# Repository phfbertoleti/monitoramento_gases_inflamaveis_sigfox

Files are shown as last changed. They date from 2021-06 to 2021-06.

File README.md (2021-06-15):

# Monitoramento de gases inflamáveis com SigFox

Este repositório contém o projeto (hardware e software) do monitoramento de gases inflamáveis com SigFox.

## Componentes

Este projeto utiliza os seguinte componentes e placas:

* Placa Edukit SigFox (link para aquisição: https://www.curtocircuito.com.br/kit-iot-sigfox-com-edukit-redfox.html), que utiliza um HT32SX para comunicação SigFox
* Placa Arduino Nano
* Sensor MQ-2
* Sensor DHT11
* Resistor de 10k / 0.25W
* Protoboard de 400 pontos
* Jumpers diversos

## Funcionamento simplificado

O funcionamento simplificado do projeto é:

1. O Arduino Nano faz, periodicamente (uma vez por segundo), a leitura dos sensores DHT11 e MQ-2.
2. Uma vez a cada meia hora o Arduino Nano envia, através do HT32SX, as leituras para a rede SigFox. A comunicação entre Arduino Nano e HT32SX é feita via UART, com comandos AT.
3. Uma vez recebido por um ou mais gateways, os dados enviados vão para o backend SigFox e redirecionados conforme callbacks configurados pelo usuário.

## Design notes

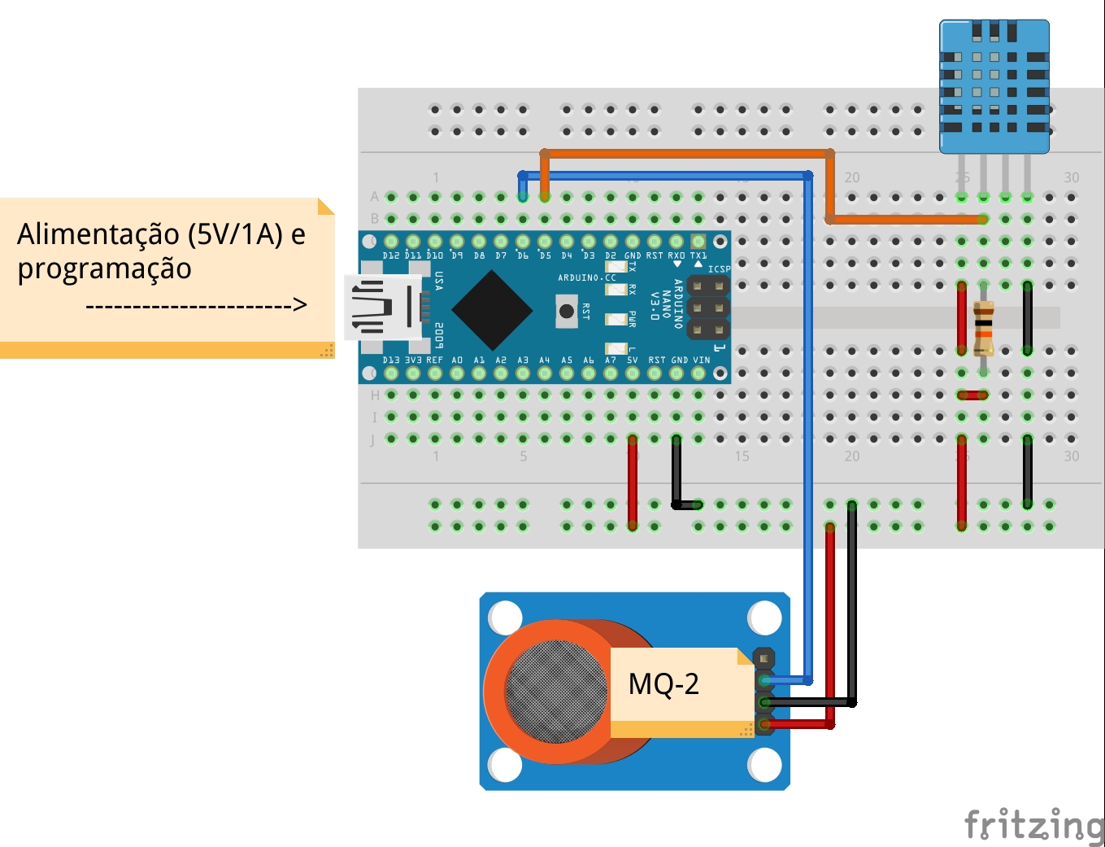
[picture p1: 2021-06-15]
hardware/esquematico_jpg.jpg

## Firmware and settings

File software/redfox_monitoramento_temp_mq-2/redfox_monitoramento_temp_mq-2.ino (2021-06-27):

/* Programa: monitoramento de temperatura ambiente e 
 *           gases inflamáveis via SigFox
 * Autor: Pedro Bertoleti
 */
#include <SoftwareSerial.h>
#include "DHT.h"

/* Definições - sensores */
#define DHTPIN                        5
#define DHTTYPE                       DHT11
#define GPIO_MQ2                      6
#define GAS_INFLAMAVEL_NAO_DETECTADO  0x00
#define GAS_INFLAMAVEL_DETECTADO      0x01
#define ESCREVE_DEBUG_SENSORES

/* Definição - breathing light */
#define TEMPO_BREATHING_LIGHT     500 //ms

/* Definição - burn-in time do MQ-2 */
#define TEMPO_BURNIN_MQ2          180 //s (3 minutos)

/* Definições - comandos AT para o HT32SX */
#define CMD_AT_HT32SX_RESET            "AT+RESET;"
#define CMD_AT_HT32SX_RCZ2             "AT+CFGRCZ=2;"
#define CMD_AT_HT32SX_MANDA_BYTES      "AT+SEND=0:" //sem downlink
#define CMD_AT_HT32SX_ENTRA_DEEP_SLEEP "AT+DEEPSLEEP;"
#define CMD_AT_HT32SX_SAI_DEEP_SLEEP   "AT+WKP;"

/* Definições - tempo entre envios SigFox */
#define TEMPO_ENTRE_ENVIOS_SIGFOX         1800000 /* 1800000ms = 30 minutos */

/* Definições - GPIOs usados na comunicação com HT32SX*/
#define RESET  4   /* Reset no HT32SX */
#define TX     2   /* Serial TX (Nano -> HT32SX) */
#define RX     3   /* Serial RX (Nano <- HT32SX) */

/* Definição - GPIO do LED */
#define LED    13 

/* Definições - baudrates das comunicações seriais */
#define BAUDRATE_SERIAL_DEBUG     115200
#define BAUDRATE_SERIAL_HT32SX    9600

/* Objeto para controle da software serial
   (para comunicação Nano <-> HT32SX */
SoftwareSerial serial_HT32SX(RX, TX);

/* Objeto para leitura do DHT11 */
DHT dht(DHTPIN, DHTTYPE);

/* Variáveis globais */
unsigned long timestamp_medicao_temp_gas;
unsigned long timestamp_envio_sigfox;
unsigned long timestamp_breathing_light;
int temperatura = 0;
char sensor_gas = GAS_INFLAMAVEL_NAO_DETECTADO;
bool led_aceso = false;
char comando_at_envio_sigfox[20] = {0};
bool alarme_gases_inflamaveis_enviado = false;

/* Protótipos */
void hardware_reset_HT32SX(void);
void envia_comando_AT_HT32SX(char * pt_comando);
unsigned long diferenca_tempo(unsigned long tref);
void aguarda_e_mostra_recepcao_HT32SX(void);
void envia_mensagem_sigfox(void);

/* Função: reseta (via hardware) o HT32SX 
 * Parâmetros: nenhum
 * Retorno: nenhum
 */
void hardware_reset_HT32SX(void) 
{
    digitalWrite(RESET, HIGH);
    delay(1000);
    digitalWrite(RESET, LOW);
    delay(100);    
}

/* Função: envia comando AT para o HT32SX
 * Parâmetros: ponteiro para string de comando
 * Retorno: nenhum
 */
void envia_comando_AT_HT32SX(char * pt_comando)
{
    char cmd_buffer[50] = {0};
    memcpy(cmd_buffer, pt_comando, strlen(pt_comando));
    serial_HT32SX.write(cmd_buffer, strlen(cmd_buffer));
    serial_HT32SX.flush();
}

/* Função: calcula a diferença entre instante atual e
 *         uma referência de tempo
 * Parâmetros: referência de tempo
 * Retorno: diferença de tempo calculada
 */
unsigned long diferenca_tempo(unsigned long tref)
{
    return (millis() - tref);
}

/* Função: aguarda recepcao de dados do HT32SX 
 *         pela UART
 * Parâmetros: nenhum
 * Retorno: nenhum
 */
void aguarda_e_mostra_recepcao_HT32SX(void)
{
    unsigned long timestamp_recepcao_serial;
    char c;
    
    timestamp_recepcao_serial = millis();
        
    while(diferenca_tempo(timestamp_recepcao_serial) <= 3000)
    {
        if (serial_HT32SX.available()) 
        {
            c = serial_HT32SX.read(); 
            Serial.print(c);
        }
    }  
}

/* Função: envia mensagem via SigFox
 * Parâmetros: nenhum
 * Retorno: nenhum
 */
void envia_mensagem_sigfox(void)
{
    /* Acorda HT32SX, faz a configuração da zona de comunicação 
       e envia mensagem SigFox */
    envia_comando_AT_HT32SX(CMD_AT_HT32SX_SAI_DEEP_SLEEP);
    aguarda_e_mostra_recepcao_HT32SX();
    hardware_reset_HT32SX();
    aguarda_e_mostra_recepcao_HT32SX();
    envia_comando_AT_HT32SX(CMD_AT_HT32SX_RCZ2);    
    aguarda_e_mostra_recepcao_HT32SX();

    /* Formata e envia comando AT */
    memset(comando_at_envio_sigfox, 0x00, sizeof(comando_at_envio_sigfox));
    sprintf(comando_at_envio_sigfox, "%s%02x%02x;", CMD_AT_HT32SX_MANDA_BYTES, 
                                                    (unsigned char)temperatura,
                                                    (unsigned char)sensor_gas);

    #ifdef ESCREVE_DEBUG_SENSORES
    Serial.print("Comando AT: ");
    Serial.println(comando_at_envio_sigfox);
    #endif
        
    envia_comando_AT_HT32SX(comando_at_envio_sigfox);
    aguarda_e_mostra_recepcao_HT32SX();
        
    /* HT32SX entra em modo sleep novamente */
    envia_comando_AT_HT32SX(CMD_AT_HT32SX_ENTRA_DEEP_SLEEP);
    aguarda_e_mostra_recepcao_HT32SX();
}

void setup() 
{
    int contador_segundos_burnin_mq2;
    
    /* Inicializa as comunicações seriais */
    Serial.begin(BAUDRATE_SERIAL_DEBUG);
    serial_HT32SX.begin(BAUDRATE_SERIAL_HT32SX);
    Serial.println("SigFox - monitor de temperatura e umidade");
    Serial.println("Aguarde 3 minutos para o burn-in time do sensor MQ-2...");

    /* Inicializa GPIOs */
    pinMode(RESET, OUTPUT);
    digitalWrite(RESET, HIGH);
    pinMode(LED, OUTPUT);
    digitalWrite(LED, LOW);
    pinMode(GPIO_MQ2, INPUT);

    /* Inicializa DHT11 */
    dht.begin();

    /* Reseta HT32SX via hardware, via software e configura zona para RCZ2*/
    hardware_reset_HT32SX();
    delay(8000);
    envia_comando_AT_HT32SX(CMD_AT_HT32SX_ENTRA_DEEP_SLEEP);

    contador_segundos_burnin_mq2 = 0;
    while (contador_segundos_burnin_mq2 < TEMPO_BURNIN_MQ2)
    {
        Serial.print("Tempo restante: ");
        Serial.print(TEMPO_BURNIN_MQ2 - contador_segundos_burnin_mq2);
        Serial.println("s");
        contador_segundos_burnin_mq2++;
        delay(1000);
    }
    
    /* Inicializa temporização da medição de: 
     * - Temperatura e umidade 
     * - Envio SigFox 
     * - Breathing light
    */
    timestamp_medicao_temp_gas = millis();
    timestamp_envio_sigfox = millis();
    timestamp_breathing_light = millis();
}

void loop() 
{
    char c;
    
    /* Escreve mensagens recebidas da UART com o HT32SX */
    if (serial_HT32SX.available()) 
    {
        c = serial_HT32SX.read(); 
        Serial.print(c);
    }

    /* Pisca breathing light */
    if (diferenca_tempo(timestamp_breathing_light) >= TEMPO_BREATHING_LIGHT)
    {
        if (led_aceso == false)
        {
            digitalWrite(LED, HIGH);
            led_aceso = true;
        }
        else
        {
            digitalWrite(LED, LOW);
            led_aceso = false;
        }
        
        timestamp_breathing_light = millis();
    }

    /* Mede a temperatura e le sensor de gas a cada segundo */
    if (diferenca_tempo(timestamp_medicao_temp_gas) >= 1000)
    {
        /* Le a temperatura atual */
        do
        {
            temperatura = (int)dht.readTemperature();
        }while( (isnan(temperatura)) || (temperatura <= 0) );

        /* Le sensor de gás MQ-2.
           Se houver gás inflamável detectado, força o envio
           de uma mensagem. */
        if (digitalRead(GPIO_MQ2) == HIGH)
        {
            sensor_gas = GAS_INFLAMAVEL_DETECTADO;

            if (alarme_gases_inflamaveis_enviado == false)
            {
                envia_mensagem_sigfox();  
                alarme_gases_inflamaveis_enviado = true;
                timestamp_envio_sigfox = millis();          
            }
        }
        else
        {
            sensor_gas = GAS_INFLAMAVEL_NAO_DETECTADO;    
            alarme_gases_inflamaveis_enviado = false;
        }

        #ifdef ESCREVE_DEBUG_SENSORES
        Serial.print("Temperatura ambiente: ");
        Serial.print(temperatura);
        Serial.println("C");

        if (sensor_gas == GAS_INFLAMAVEL_DETECTADO)
        {
            Serial.println("Gas inflamavel: detectado!");
        }
        else
            Serial.println("Gas inflamavel: nada detectado");    
            
        Serial.println("------");
        #endif

        timestamp_medicao_temp_gas = millis();
    }

    /* Verifica se é o momento de enviar medições via SigFox */
    if (diferenca_tempo(timestamp_envio_sigfox) >= TEMPO_ENTRE_ENVIOS_SIGFOX)
    {
        envia_mensagem_sigfox();
        timestamp_envio_sigfox = millis();
    }
}

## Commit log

2021-06-15 Primeiro commit
    [esquematico.fzz]
2021-06-15 Atualização da lista de componentes
2021-06-23 Adicionado envio de mensagem emergencial em caso de gases inflamáveis/fumaça detectados
2021-06-26 Acrescentado burn-in time do sensor MQ-2
    [redfox_monitoramento_temp_mq-2.ino]
2021-06-27 Corrigida descrição do software
    [redfox_monitoramento_temp_mq-2.ino]
